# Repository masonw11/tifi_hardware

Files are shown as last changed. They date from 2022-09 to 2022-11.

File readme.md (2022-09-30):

## Attributions
This project contains design files obtained from [SnapEDA](https://www.snapeda.com/home/). These models are used as-is. SnapEDA permits publicly redistributing up to 10 models.

SnapEDA licenses these models under a Creative Commons Attribution-ShareAlike 4.0 International License (CC BY-SA) with Design Exception 1.0. This license can be found in the project wherever their models are included.

The following models in the project were obtained from SnapEDA:
- [SM04B-SRSS-TB(LF)(SN)](https://www.snapeda.com/parts/SM04B-SRSS-TB(LF)(SN)/JST%20SALES%20AMERICA%20INC%20(VA)/view-part/?ref=digikey) (also referred to as STEMMA QT within the project)
- [SHT40-AD1B-R2](https://www.snapeda.com/parts/SHT40-AD1B-R2/Sensirion/view-part/?ref=digikey)

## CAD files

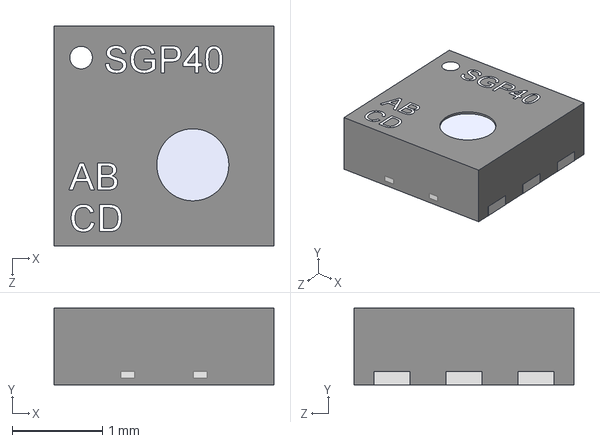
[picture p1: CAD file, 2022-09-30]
kicad_libraries/3dmodels/SGP40/Sensirion_Gas_Sensors_Software_GAS_CD_SGP40_STEP_File.step
2.44 x 0.852 x 2.44 mm

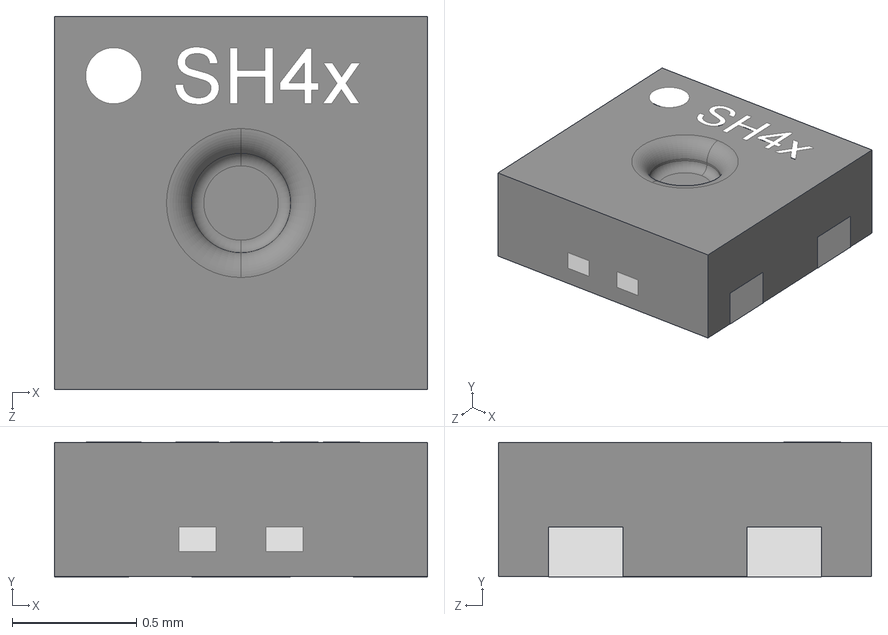
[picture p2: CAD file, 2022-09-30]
kicad_libraries/3dmodels/SHT40/SHT40-AD1B-R2.step
1.50 x 0.542 x 1.50 mm

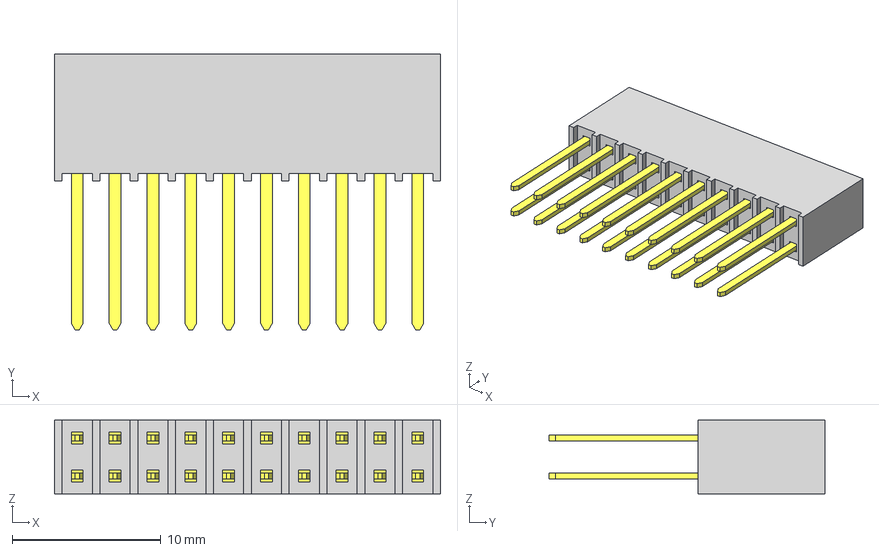
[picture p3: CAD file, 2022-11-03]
kicad_libraries/3dmodels/SSW-110-23-F-D/SSW-110-23-F-D.stp
25.9 x 18.5 x 4.95 mm
P2SSW-110-23-F-D
T1SSW-110-23-F-D

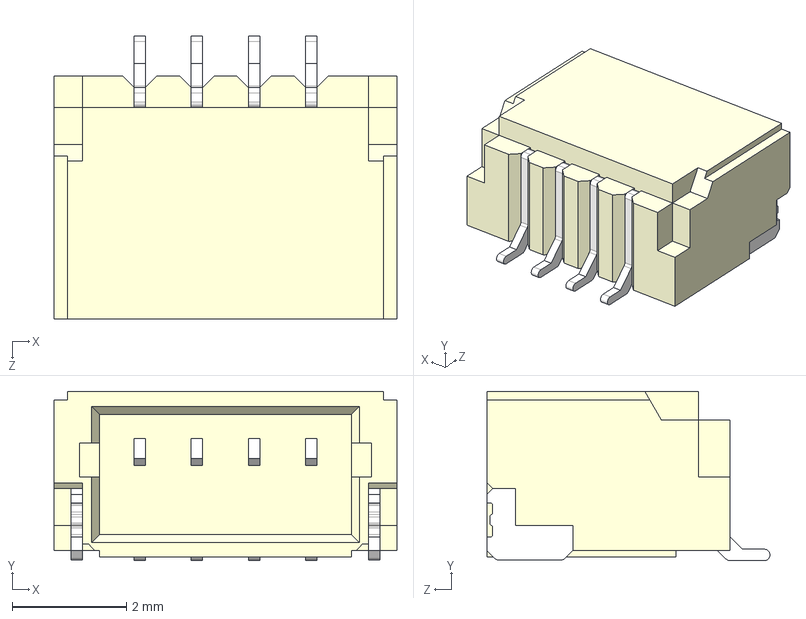
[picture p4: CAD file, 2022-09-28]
kicad_libraries/3dmodels/STEMMA QT/SM04B-SRSS-TB_LF__SN_.step
6.00 x 2.96 x 4.95 mm

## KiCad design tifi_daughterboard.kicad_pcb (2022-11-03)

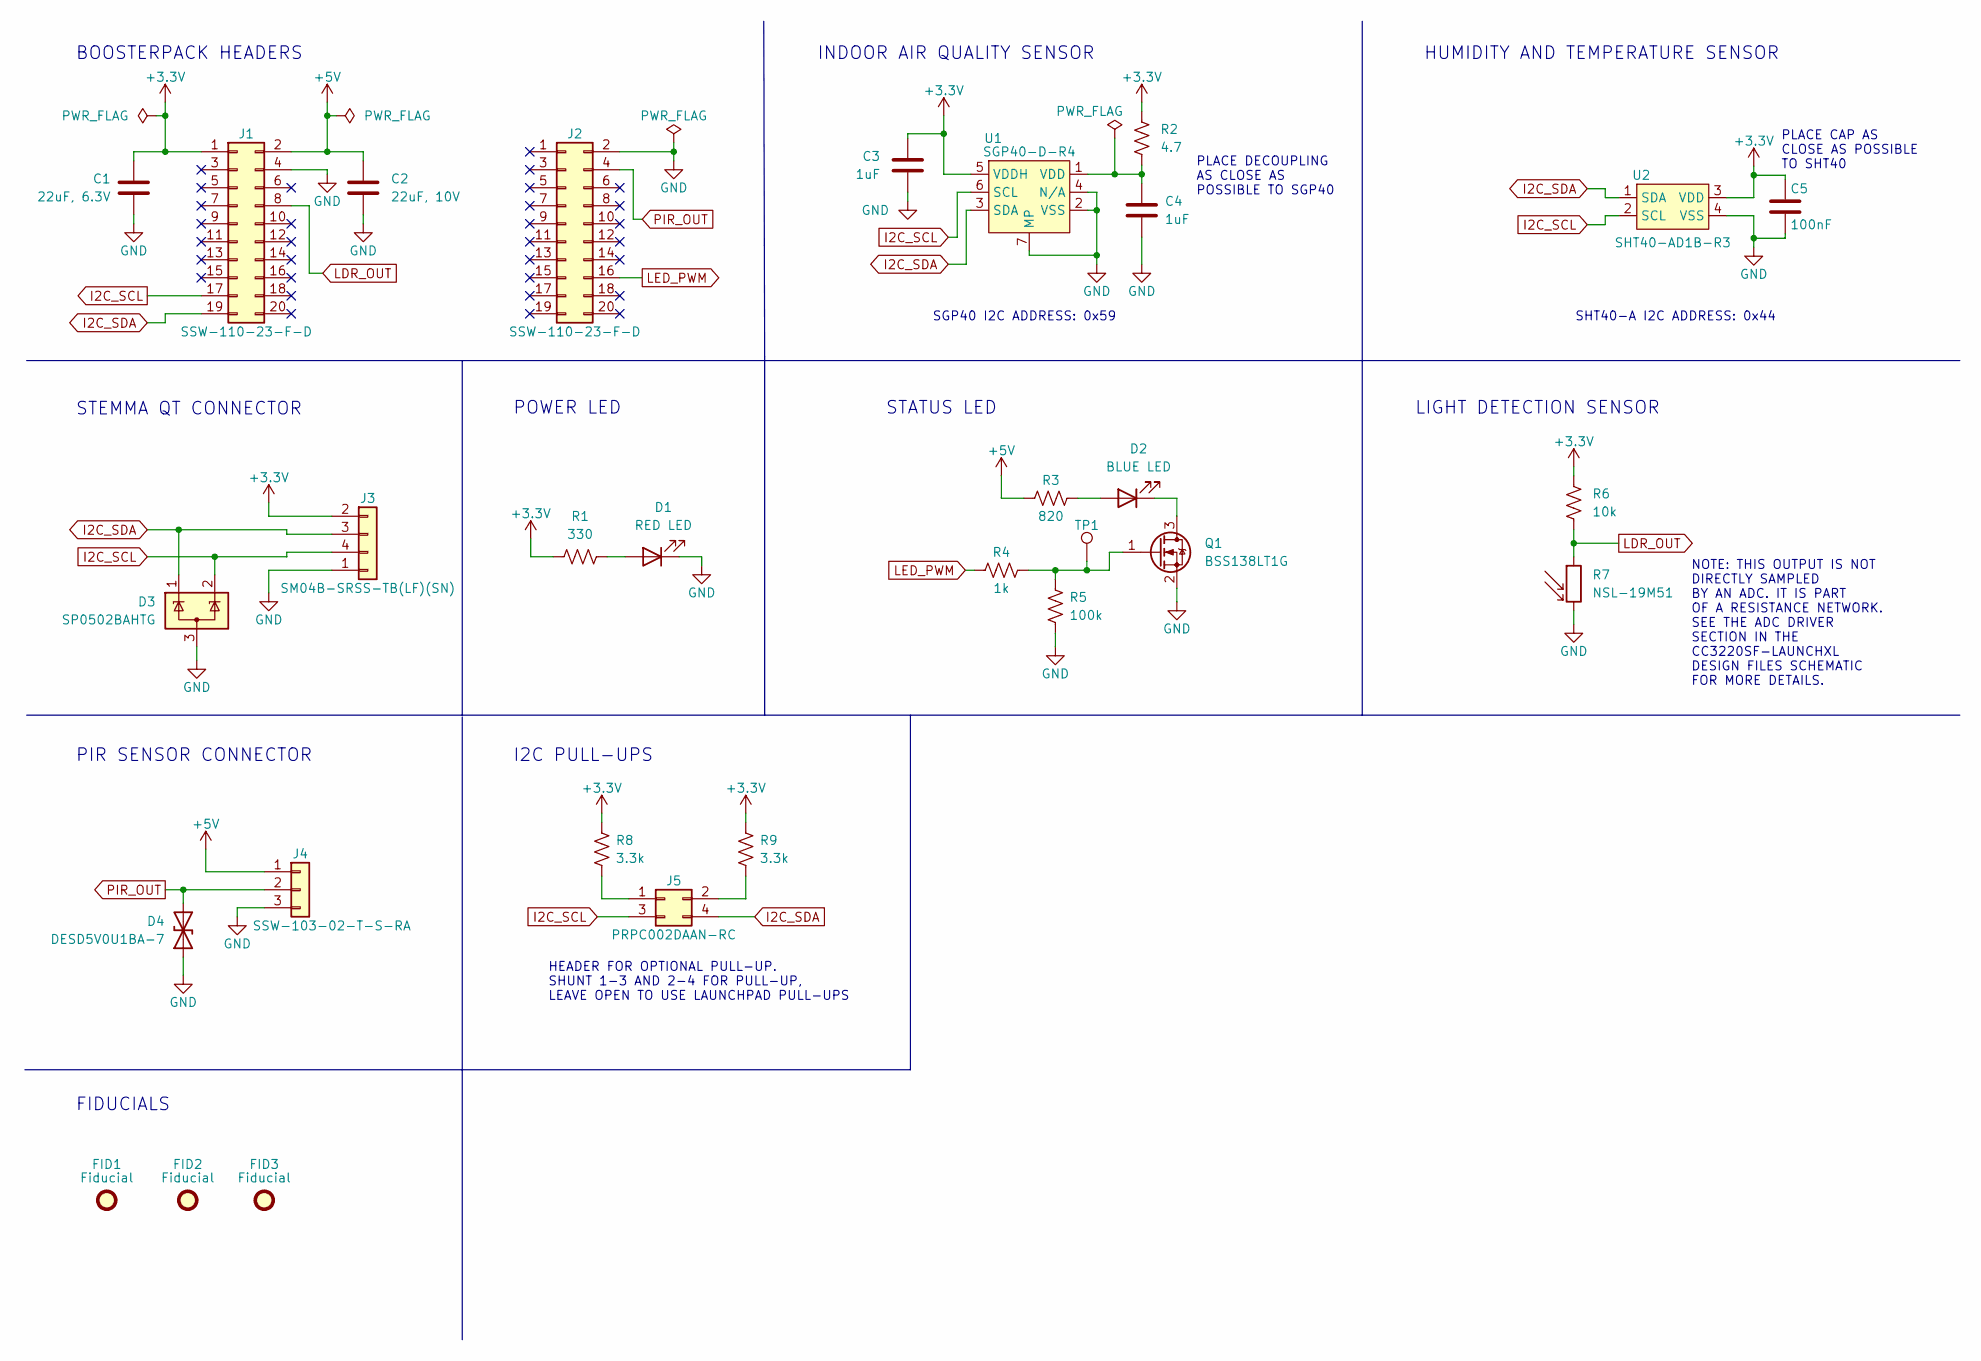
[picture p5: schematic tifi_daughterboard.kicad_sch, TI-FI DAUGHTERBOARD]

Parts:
C1: 22uF, 6.3V; C_1206_3216Metric
C2: 22uF, 10V; C_1206_3216Metric
C3, C4: 1uF; C_0805_2012Metric
C5: 100nF; C_0805_2012Metric
D1: RED LED; LED_0805_2012Metric_Pad1.15x1.40mm_HandSolder
D2: BLUE LED; LED_0805_2012Metric_Pad1.15x1.40mm_HandSolder
D3: SP0502BAHTG; SOT-23
D4: DESD5V0U1BA-7; D_SOD-323
FID1, FID2, FID3: Fiducial; Fiducial_1mm_Mask2mm
J1, J2: SSW-110-23-F-D; PinHeader_2x10_P2.54mm_Vertical
J3: SM04B-SRSS-TB(LF)(SN); JST_SM04B-SRSS-TB(LF)(SN)
J4: SSW-103-02-T-S-RA; PinSocket_1x03_P2.54mm_Horizontal
J5: PRPC002DAAN-RC; PinHeader_2x02_P2.54mm_Vertical
Q1: BSS138LT1G; SOT-23
R1: 330; R_0805_2012Metric
R2: 4.7; R_0805_2012Metric
R3: 820; R_0805_2012Metric
R4: 1k; R_0805_2012Metric
R5: 100k; R_0805_2012Metric
R6: 10k; R_0805_2012Metric
R7: NSL-19M51; R_LDR_4.9x4.2mm_P2.54mm_Vertical
R8, R9: 3.3k; R_0805_2012Metric
TP1: TestPoint; TestPoint_THTPad_D1.5mm_Drill1.0mm
U1: SGP40-D-R4; DFN-6-1EP_2.44x2.44mm_P0.8mm_EP1.25x1.7mm
U2: SHT40-AD1B-R3; XDCR_SHT40-AD1B-R2

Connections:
+3.3V: C1.1, C3.1, C5.1, J1.1, J3.2, R1.1, R2.1, R6.1, R8.1, R9.1, U1.5 (VDDH), U2.3 (VDD)
+5V: C2.1, J1.2, J4.1, R3.1
GND: C1.2, C2.2, C3.2, C4.2, C5.2, D1.1 (K), D3.3 (A), D4.1 (A1), J1.4, J2.2, J3.1, J4.3, Q1.2 (S), R5.2, R7.2, U1.2 (VSS), U1.4 (N/A), U1.7 (MP), U2.4 (VSS)
I2C_SCL: D3.2 (K), J1.17, J3.4, J5.3, U1.6 (SCL), U2.2 (SCL)
I2C_SDA: D3.1 (K), J1.19, J3.3, J5.4, U1.3 (SDA), U2.1 (SDA)
LDR_OUT: J1.8, R6.2, R7.1
LED_PWM: J2.16, R4.1
unnamed: C4.1, R2.2, U1.1 (VDD)
unnamed: D1.2 (A), R1.2
unnamed: D2.1 (K), Q1.3 (D)
unnamed: D2.2 (A), R3.2
unnamed: J5.1, R8.2
unnamed: J5.2, R9.2
unnamed: Q1.1 (G), R4.2, R5.1, TP1.1
PIR_OUT: D4.2 (A2), J2.4, J4.2

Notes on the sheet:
POWER LED
PLACE DECOUPLING AS CLOSE AS POSSIBLE TO SGP40
SHT40-A I2C ADDRESS: 0x44
SGP40 I2C ADDRESS: 0x59
STATUS LED
PLACE CAP AS CLOSE AS POSSIBLE TO SHT40
LIGHT DETECTION SENSOR
PIR SENSOR CONNECTOR
STEMMA QT CONNECTOR
HUMIDITY AND TEMPERATURE SENSOR
INDOOR AIR QUALITY SENSOR
BOOSTERPACK HEADERS
HEADER FOR OPTIONAL PULL-UP. SHUNT 1-3 AND 2-4 FOR PULL-UP, LEAVE OPEN TO USE LAUNCHPAD PULL-UPS
NOTE: THIS OUTPUT IS NOT DIRECTLY SAMPLED BY AN ADC. IT IS PART OF A RESISTANCE NETWORK. SEE THE ADC DRIVER SECTION IN THE CC3220SF-LAUNCHXL DESIGN FILES SCHEMATIC FOR MORE DETAILS.
FIDUCIALS
I2C PULL-UPS

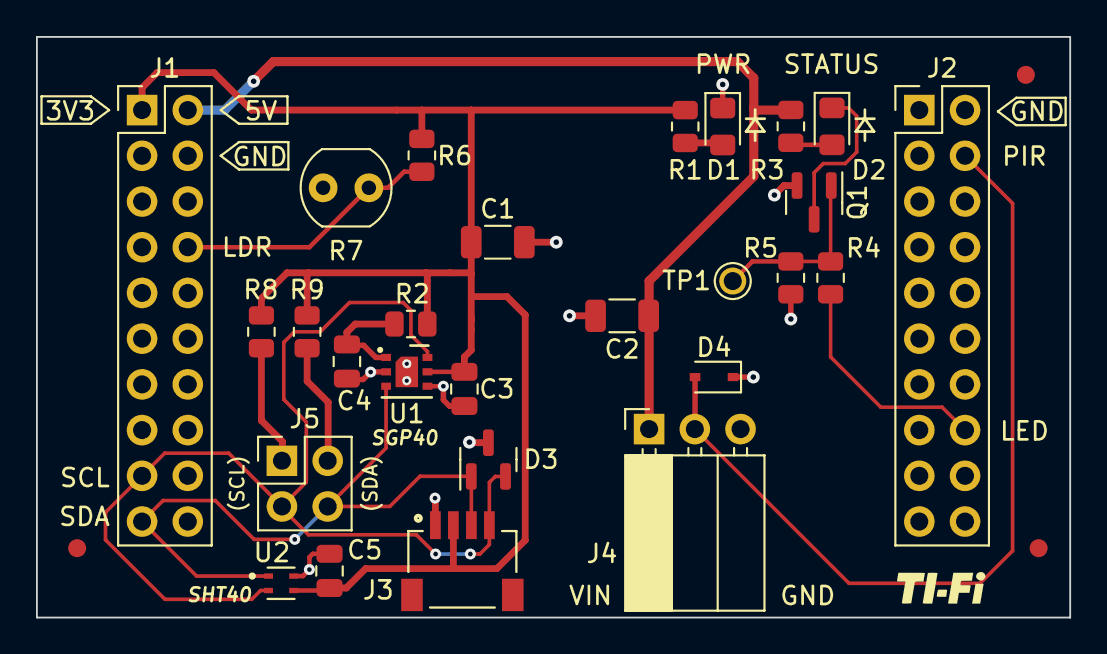
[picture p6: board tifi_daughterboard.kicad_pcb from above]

Board: 2 copper layers, 57.4 x 32.3 mm, 30 parts (0 on the bottom side), 15 nets.

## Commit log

2022-09-01 Initial commit of project files.
    [tifi_daughterboard.kicad_pcb, tifi_daughterboard.kicad_sch]
2022-09-01 Add BoosterPack headers to schematic.
    [tifi_daughterboard.kicad_sch]
2022-09-01 Add SGP40 to schematic.
    [tifi_daughterboard.kicad_sch]
2022-09-02 Add SHT40 and todos to schematic.
    [tifi_daughterboard.kicad_sch]
2022-09-15 added ldr symbol
    [tifi_daughterboard.kicad_sch]
2022-09-15 Added PIR and Testpoint, haven't annotated or footprinted yet
    [tifi_daughterboard.kicad_sch]
2022-09-15 Changed the input/output of the ldr
    [tifi_daughterboard.kicad_sch]
2022-09-20 Updating PIR circuit
    [tifi_daughterboard.kicad_sch]
2022-09-20 Added the values for the regulator components
    [tifi_daughterboard.kicad_sch]
2022-09-20 added footprints
    [tifi_daughterboard.kicad_sch]
2022-09-22 Added JST connector for stemma
    [tifi_daughterboard.kicad_sch]
2022-09-27 Change STEMMA QT connector.
    The previous connector had 2mm pitch, changed to 1mm pitch.
    [tifi_daughterboard.kicad_sch]
2022-09-27 Corrected pitch on BoosterPack headers footprint.
    The previous pitch is 1mm, needed to be 2.54mm.
    [tifi_daughterboard.kicad_sch]
2022-09-27 Update PIR sensor connector.
    [tifi_daughterboard.kicad_sch]
2022-09-28 Increase section labels to 70 mils.
    [tifi_daughterboard.kicad_sch]
2022-09-28 Various polish fixes and ADC pin correction.
    Removed unused net label.
    Added NC flags to headers.
    Moved LDR circuit output to ADC pin supported on the CC3220SF LaunchPad.
    Update LDR symbol and footprint to use KiCad built-ins.
    [tifi_daughterboard.kicad_sch]
2022-09-28 Add STEMMA QT footprint and attributions.
    [SM04B-SRSS-TB_LF__SN_.step, tifi_daughterboard.kicad_sch]
2022-09-29 Light level sensor fix.
    Output was previously obtained from a net connected to GND.
    The design now uses a voltage divider.
    [tifi_daughterboard.kicad_sch]
2022-09-29 Generic cleanup.
    Removed test points temporarily until schematic is feature-complete.
    Added PWR_FLAG to BoosterPack power pins for ERC check.
    [tifi_daughterboard.kicad_sch]
2022-09-29 Assign parts to BP headers. Add power LED.
    [tifi_daughterboard.kicad_sch]
2022-09-30 Add indicator LED circuit.
    [tifi_daughterboard.kicad_sch]
2022-09-30 Add series gate resistor to LED PWM circuit.
    [tifi_daughterboard.kicad_sch]
2022-09-30 Annotate schematic references
    [tifi_daughterboard.kicad_sch]
2022-09-30 Assign footprints to discrete components.
    [tifi_daughterboard.kicad_sch]
2022-09-30 Create SGP40 footprint
    [Sensirion_Gas_Sensors_Software_GAS_CD_SGP40_STEP_File.step]
2022-09-30 Add SHT40 SnapEDA model. Assign footprint.
    [SHT40-AD1B-R2.step, tifi_daughterboard.kicad_sch]
2022-09-30 Rough layout draft.
    [tifi_daughterboard.kicad_pcb, tifi_daughterboard.kicad_sch]
2022-09-30 Routing start
    [tifi_daughterboard.kicad_pcb]
2022-09-30 Complete routing, still some TODOs.
    TODOS include:
    Test pads / points
    Reduce vias on I2C signals?
    TVS diodes on connectors
    Shunt option for blue LED (bypass PWM)
    Optional I2C pullups
    [tifi_daughterboard.kicad_pcb]
2022-10-01 Move to 4-layer stackup.
    [tifi_daughterboard.kicad_pcb]
2022-10-01 Start 4-layer routing.
    [tifi_daughterboard.kicad_pcb]
2022-10-02 Revert to two layers. Move PIR sensor output.
    [tifi_daughterboard.kicad_pcb, tifi_daughterboard.kicad_sch]
2022-10-02 Reposition STEMMA QT to bottom of board.
    [tifi_daughterboard.kicad_pcb]
2022-10-02 Move VOC sensor closer to header.
    [tifi_daughterboard.kicad_pcb]
2022-10-02 Route I2C connections.
    [tifi_daughterboard.kicad_pcb]
2022-10-02 Route 5V rail
    [tifi_daughterboard.kicad_pcb]
2022-10-02 Route remaining components.
    [tifi_daughterboard.kicad_pcb]
2022-10-02 Adjust LED placement.
    [tifi_daughterboard.kicad_pcb]
2022-10-02 Add alignment silkscreen.
    [tifi_daughterboard.kicad_pcb]
2022-10-02 Add testpoint for LED driver FET gate.
    [tifi_daughterboard.kicad_pcb]
2022-10-02 Zone fill update for test point.
    [tifi_daughterboard.kicad_pcb]
2022-10-02 Add TVS diodes to connectors.
    [tifi_daughterboard.kicad_pcb, tifi_daughterboard.kicad_sch]
2022-10-02 Add useful info to silkscreen layer
    [tifi_daughterboard.kicad_pcb]
2022-10-02 Add optional I2C pullups.
    [tifi_daughterboard.kicad_pcb, tifi_daughterboard.kicad_sch]
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2022-10-03 Add mask clearance and supplier link fields.
    [tifi_daughterboard.kicad_pcb, tifi_daughterboard.kicad_sch]
2022-10-03 Add bulk capacitors to schmatic and board.
    [tifi_daughterboard.kicad_pcb, tifi_daughterboard.kicad_sch]
2022-10-03 Add board fiducials and pad to SGP40 symbol.
    [tifi_daughterboard.kicad_pcb, tifi_daughterboard.kicad_sch]
2022-10-04 Schematic cleanup, minor board fixes.
    [tifi_daughterboard.kicad_pcb, tifi_daughterboard.kicad_sch]
2022-10-06 Add purchase links for each component.
    [tifi_daughterboard.kicad_sch]
2022-10-06 Sync PCB with schematic changes.
    [tifi_daughterboard.kicad_pcb, tifi_daughterboard.kicad_sch]
2022-10-06 Export gerbers for Rev0
    [tifi_daughterboard-B_Cu.gbr, tifi_daughterboard-B_Mask.gbr, tifi_daughterboard-B_Paste.gbr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]
2022-10-06 Add voltage rating to bulk caps
    These caps were being collated in the BOM.
    They have seperate max voltage ratings.
    [tifi_daughterboard.kicad_sch]
2022-10-06 Update PCB with new capacitor values.
    [tifi_daughterboard.kicad_pcb]
2022-11-02 Fix GND label on back silkscreen.
    [tifi_daughterboard.kicad_pcb]
2022-11-02 Add diode symbol for LEDs. Reposition I2C labels.
    [tifi_daughterboard.kicad_pcb]
2022-11-02 Increase net label spacing for J4.
    [tifi_daughterboard.kicad_pcb]
2022-11-02 Change Q1 symbol to standard GSD pin numbering.
    [tifi_daughterboard.kicad_pcb]
2022-11-02 Change minimum trace width to 8 mils.
    [tifi_daughterboard.kicad_pcb]
2022-11-03 Update schematic to reflect correct Q1 numbering.
    [tifi_daughterboard.kicad_sch]
2022-11-03 Add OSHW logo to back silkscreen.
    [tifi_daughterboard.kicad_pcb]
2022-11-03 Bump to revision 1.
    [tifi_daughterboard.kicad_pcb, tifi_daughterboard.kicad_sch]
2022-11-03 Move J5 away from J1, increase label size.
    [tifi_daughterboard.kicad_pcb]
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2022-11-03 Fix overlapping courtyards.
    [tifi_daughterboard.kicad_pcb]
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2022-11-03 Add correct 3D model for BoosterPack headers.
    [SSW-110-23-F-D.stp, tifi_daughterboard.kicad_pcb]
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

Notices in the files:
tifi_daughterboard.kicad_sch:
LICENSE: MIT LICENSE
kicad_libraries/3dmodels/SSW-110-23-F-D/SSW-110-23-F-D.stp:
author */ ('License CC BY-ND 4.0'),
